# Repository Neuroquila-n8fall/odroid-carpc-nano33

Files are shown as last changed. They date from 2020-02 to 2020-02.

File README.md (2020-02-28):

# odroid-carpc-nano33
Derivate of odroid-carpc-due for the Arduino Nano 33 IoT
An Arduino Due project for controlling an Odroid N2 via BMW Keyfob and iDrive.

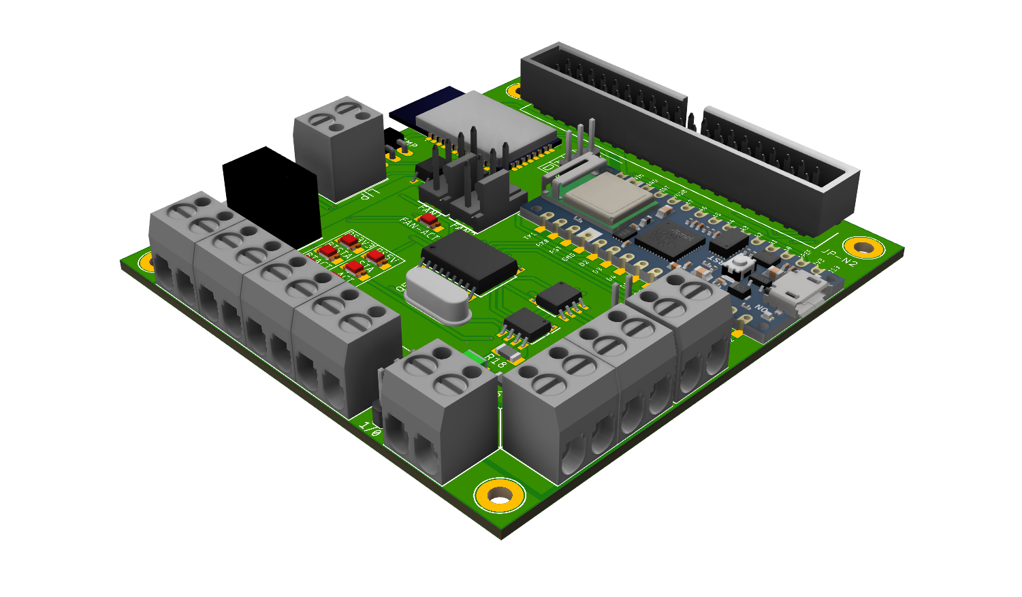
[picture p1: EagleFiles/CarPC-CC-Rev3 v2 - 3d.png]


## Hardware used
- BMW 1-Series 2009
- Arduino Nano 33 IoT
- Custom board design to incoorporate MCU, Bluetooth and Canbus logic on the same board
- iDrive 7-Button Controller 
- DS18B20 Temperature Probe
- LTC3780 Power Supply Module

## Purpose
This project is intended to support an Odroid N2 in its function as a car-pc. This also involves controlling the display brightness of the Vu7+ display by applying PWM signals to its backlight chip by reacting on the cars' light sensor on the windscreen.
As a bonus it's designed to support an iDrive controller as an input device for the Odroid to have comfortable access to the car-pc functions. To make it function properly an app called "Button Mapper" is used to react on F-Keys.
See: https://play.google.com/store/apps/details?id=flar2.homebutton

## Electrical Details
The brainbox of this module is a Arduino Nano 33 IoT which has its own 3v3 voltage regulator on board. To reduce stress it is supplied by the onboard 5V regulator from Recom. This 5V supply also powers the TJA1050 controller which needs 5V in order to generate the signals on the CAN-Bus. The Bluetooth module, MCP2515 and INA219 are supplied by the Arduino's voltage regulator.

The 5V Regulator is supplied by an external power supply and tolerates a maximum of 12V.

Because of the internal wiring of the Arduino, even the Fans will work when the Arduino is powered via USB. You will read 3V on the 12V rail if only the Arduino is plugged in to a Supply via USB. I've missed to include a Schottky Diode in order to prevent this behavior but it doesn't hurt either because everything is on the same potential and the internal regulator of the Arduino can deliver 1A continously. This also enables you to diagnose things on desk without hooking up everything to a external DC supply.

### Part selection
When selecting parts I've focused to select hose which are either AECQ100 certified or have an extended operating temperature range until at least 85°C. You should select parts for automotive use to ensure they last as long as possible.
```diff
- ATTENTION: Contrary to the schematics and board, the TCMT1100 up to TCMT1102 optocouplers can be used.
The TCMT1104 requires 10mA to trigger which the SAMD21 can't deliver. It's maximum current on a pin is 7mA
```
### Fan sockets
The PWM signal is tuned to work with all fans. I've tested bog standard 120mm fans as well as a dual high-pressure cisco switch fan. Please note that the socket delivers the voltage from the 12V rail. There is no possibility to power 5V fans here.

## 3rd Party Libraries used
I'm using a modified version of the BPLib that now supports sending and holding multiple keys. That's probably important for future tweaks. The original library only supports sending one single key and modifiers.
See: https://github.com/Neuroquila-n8fall/BPLib

Also: Seeedstudios Canbus Shield library
See: https://github.com/Seeed-Studio/CAN_BUS_Shield

## Usage
### Intended Usage & prerequisites
The main key aspect of the layout is to connect an external power supply which is supplied by the battery of the car through the board. The intention behind this is to keep everything safely connected. Cars are very flammable and therefore the top priority has to be that there is no risk of loose, uninsulated wires dangling around!

A DS18B20 temperature probe is required in order to keep track of the temperatures of the pc and control the fans accordingly.

### Wiring
This new revision has everything on board which makes wiring very easy. It also minimizes the amount of wiring.
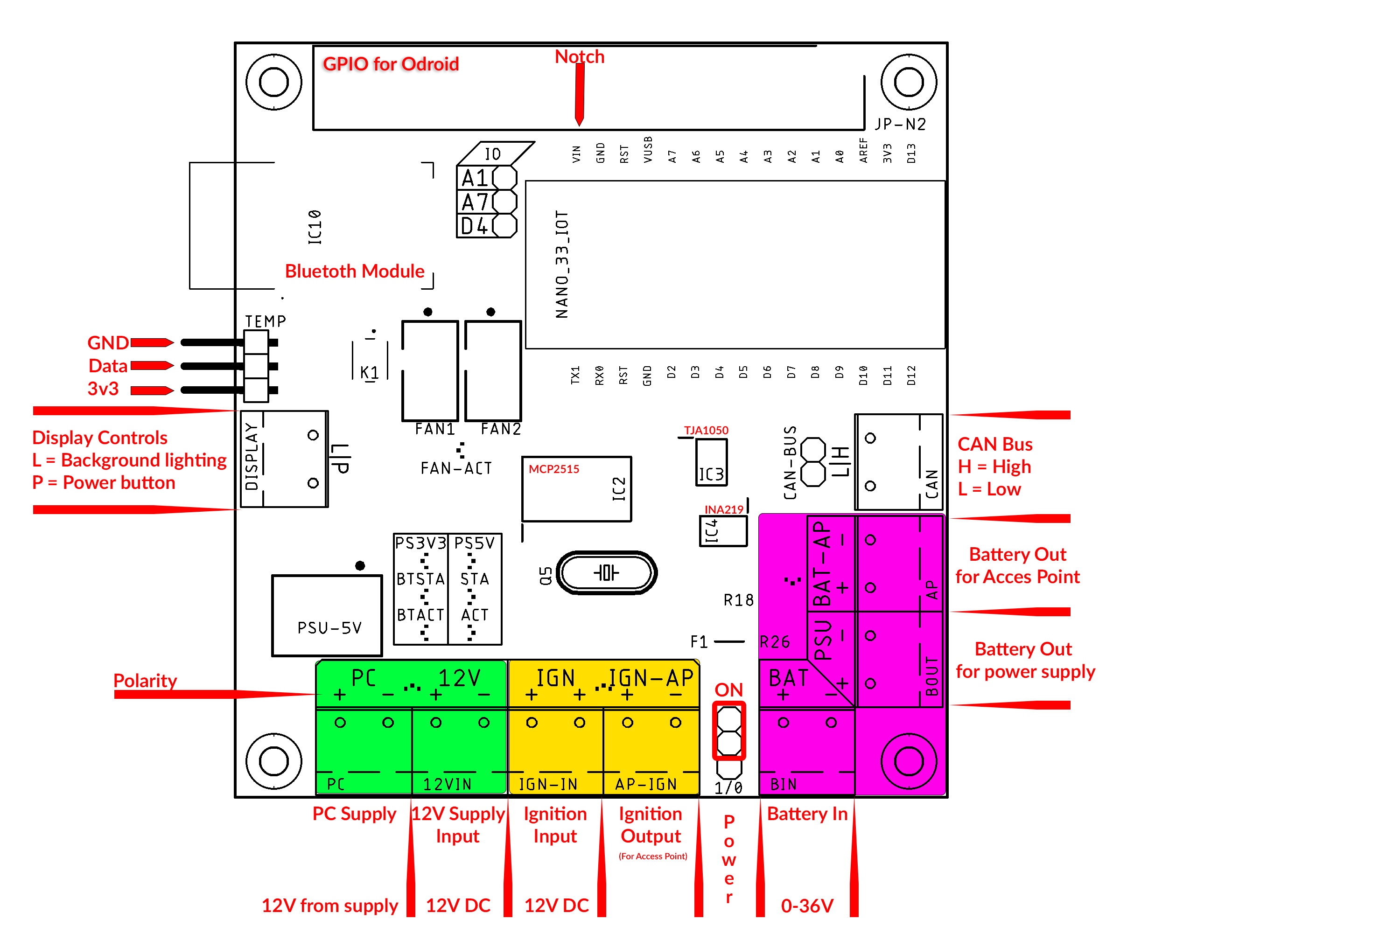
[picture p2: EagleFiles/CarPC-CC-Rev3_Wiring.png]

All of the terminals have a Description on the bottom which usually is hidden by the terminal itself. That's why a more descriptive text is added to the top.
You'll find a Terminal for the following auxillary devices:
- Display (VU7A+): One Output for controlling the background lighting and one for triggering the power button
- CAN-Bus: You can hook up your K-Can to the screw terminal or the pin headers behind.
- PC: This is the output for the Odroid. It receives power directly from the 12V terminal
- 12V: Power supply input from an external regulated power supply. I heavily recommend a supply board with the LTC3780 chip.
- IGN: Ignition. Two terminals are available because we only need one positive input. In case you want to hook up something on the ignition, this is the right place
- IGN-AP: Ignition output for Access Points. I'm using the Teltonika RUT850 which needs this supply in order to power up and down on itself
- BAT: Battery Input. Used by the control logic to check for voltage levels and also delivers power to the DC Supply
- PSU (BOUT): Battery Out. Intended to be used as Output to the power supply. This Terminal is switched by the "1/0" pin header between"IGN-AP2 and "BAT"
- BAT-AP: Used by the Teltonika access point as permanent supply

#### Color blocks explained
- Green: Shared 12v Rail
- Orange/Yellow: Shared Ignition Rail
- Purple: Shared Battery Rail

### Parameters
Parameters are described inside the source file "main.h" (https://github.com/Neuroquila-n8fall/odroid-carpc-nano33/blob/master/src/main.h)
Everything is well tested and works right out of the box. The prototype is already reaching one year of service on my car and shares the same code base.

### I2C
There are two solder pads "SCL-N" and "SDA-N" on the bottom to be bridged when you want to establish I2C communication between the Odroid N2 and the Arduino. This will join the N2 to the Arduino I2C bus. Important: The Arduino is the bus master!
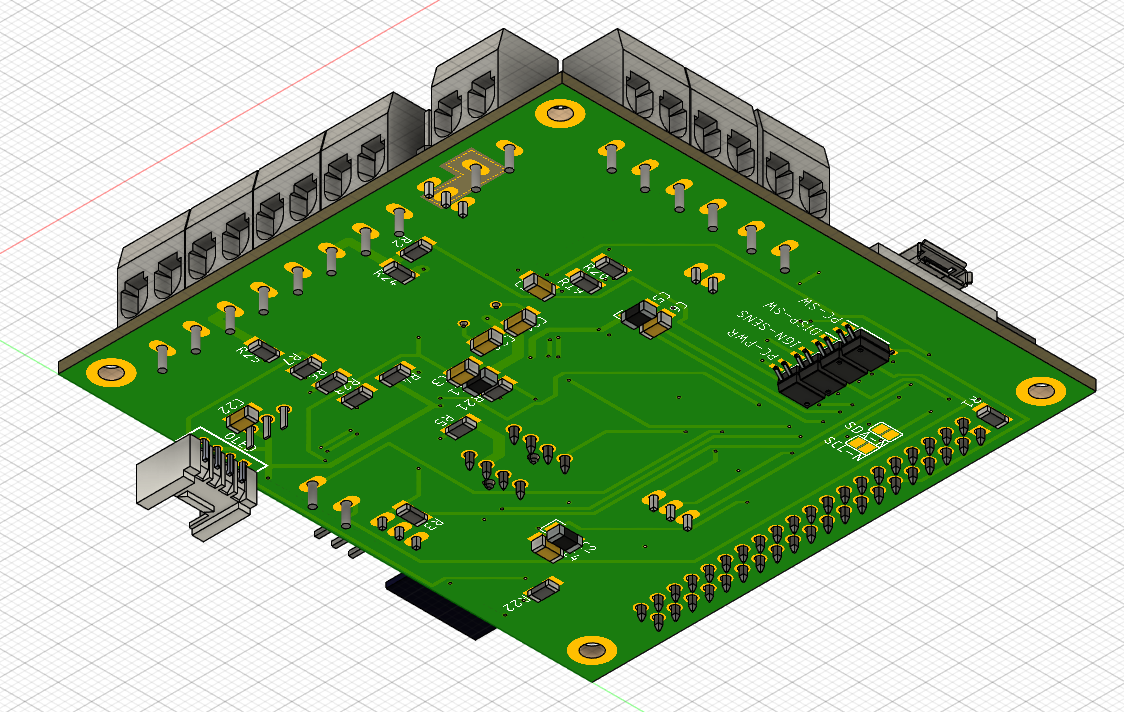
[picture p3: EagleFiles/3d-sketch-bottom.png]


### First-Run
#### Bluetooth Module Setup
Before uploading the sketch to the Arduino, you should head over to the setup section and uncomment the line "initalSetup()". Then, head over to the function and customize the name of the device and PIN. This will then set the required settings on the next startup of the Arduino on the bluetooth module so it works as intended. You may also use a Serial redirection sketch to enter the commands yourself or tweak things.
After that you should comment the section again and re-upload the sketch.

## Functions & Behaviour
### Startup
When you open the car by keyfob, the PC will be started by pulling down the power button GPIO pin on the Odroid for a second. This will turn on the Odroid.
### Shutdown
When you close the car by keyfob, it will pull down the GPIO pin again but now for several seconds which triggers the shutdown routine of the Odroid so it shuts down gracefully.
### Queuing
You can queue exactly one action by pressing "open" or "close" on the keyfob respectively. 

What does this mean? 

This means that if you want to take something out of the car and leave it again, you will have to press "open" and "close" in a rather short timespan. usually this would mean the startup process will be terminated or the PC will run until you enter the car again or press the "close" button again after the Pc booted up. Instead the controller stores the second action and waits for the PC to boot up and then shuts it down gracefully again. Because we never now when a "open" is followed by driving or just for accessing the car for a short duration this system prevents ungraceful shutdowns or battery drain.

Vice-Versa this means when closing the car and re-opening it again, the Odroid will be started again shortly. 
### Battery Monitoring (WIP)
- If the battery drops below a certain voltage, the Odroid will be shut down gracefully
- Fans will be shut down
- Everything else stays active. I'm planning to save energy by only enabling WiFi if the ignition is on.
### WiFi
- Wifi is included and active and intended to provide IoT functionality in the future. I have yet to think about useful scenarios where this feature comes in handy
- As of now WiFi is used to synchronize the RTC via NTP
### iDrive Controls
If an iDrive Controller is placed on the CAN Network, the controller will start to communicate with the network. The Sketch has the correct facilities in place to keep it awake and enable the rotation encoder. I've tried to resemble the original behavior of the iDrive controller.
- Rotation is scrolling up and down respectively
- Pushing the Menu button or the knob equals "Enter"
- Pushing the knob in any direction will emulate a directional arrow key so you can navigate in two dimensions between UI elements.

Things worthy of noting:
- Some apps don't come with keyboard support. Android is a touch-centric OS and therefore only a few devs implement full fledged keyboard control. Apps that work well are: Sygic, Spotify, Torque, Google Maps, Chrome
- You should use the button mapper app to implement extended features like return to home by long press and stuff like that
- Mapping buttons to apps can be done via Odroid Settings
### Multi Function Steering Wheel Buttons
Native support is integrated which means you can skip music tracks with the arrow keys and fast-forward and rewind when holding those buttons.
### Display Brightness Adjustment
The controller fetches messages from the CAN network from the RLS module (Regen Licht Sensorik) which sits, if fitted, on the windscreen behind the rearview mirror. It then maps those values to control the screen brightness of the VU7a display. The control values are proven but may vary between cars.

## Signalling & Diagnosis
There are plenty of status led on the board:
- One for the battery rail which indicates that the battery is connected
- One for the 12v rail to indicate a working power supply input
- One for the ignition rail so you know if the ignition input works
- One for the 3v3 and 5v rails 
- 2 for the bluetooth module: BTACT = Activity: Tells you what the module is doing, BTSTA = Status: Off when a device is connected
- 2 for the Arduino: STA tells you if the PC is running, ACT tells you if there is activity on the CAN-Bus and pulses when nothing is going on
- One for the fans: On if the relay is opened and fans are enabled
- There is also an optional OLED Grove connector. Because of timing issues I removed it from the project but it can be used as a diagnostical device if needed. Since 5v and I2C is supplied there, you can hook up other stuff to this port.

## Known Issues
- ~~As soon as the car battery is depleted, the arduino will write value 0 to the display brightness pin when the engine starts or doors are fully opened and closed. I have yet to understand why on earth this is happening even when the engine is already running. I can only think of a solution where the brightness is updated frequently, like 10 seconds or so.~~

**Solved: Explicit correction of values that are out of range. When the car has recovered from a very low voltage level, the light sensor reports values that are not mapped correctly by the "map" function. Such values are now being overwritten**
- ~~When the car is not shut and goes into hibernation and the car pc is still running, it might happen that the display goes dark. This might also be related to the aforementioned problem and may point to an integer overflow issue on the brightness calculation. Maybe the sensor on the windshield (RLS Control Module) sends some crazy data when it goes into hibernation.~~

**Solved: Same issue and solution as above**

- Sometimes the "restart" feature of the queuing mechanism doesn't work. Odroid will then start after the ignition is on.

- Apparently setting the PWM clock to 25kHz in order to control PWM fans also affects the display brightness pin somehow. This is something I didn't see coming. Maybe another pin configuration is needed...

## Questions I got asked...
Why all the hassle if I could just simply upgrade the car to the official iDrive?
Because I always felt the need to include a full blown car pc into my car. Upgrading to iDrive wasn't an option due to the fact that this system is just too limited. If I had a recent model, this wouldn't be a problem but sitting on a rather "old" car leaves one without options. I want a browsable music library with cloud sync, internet, the precious Torque app, ...all the good stuff!
The icing on the cake was the decision to go the extra mile and swap the center console and install an iDrive 7-Button control unit. It looks like OEM but it does much, much more.

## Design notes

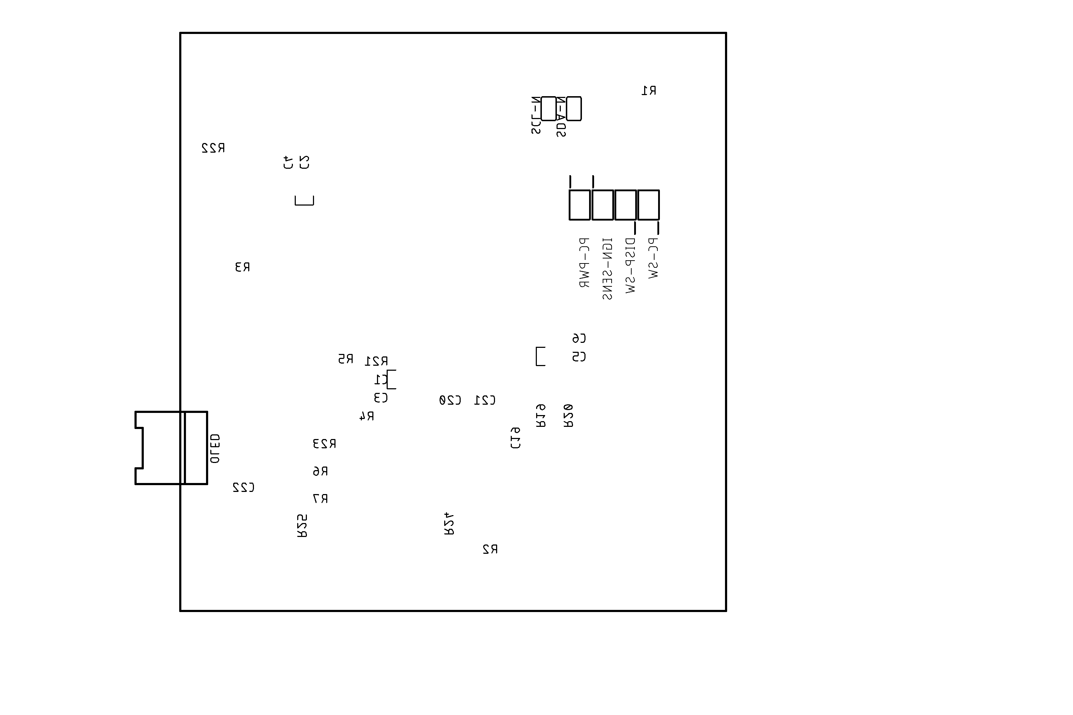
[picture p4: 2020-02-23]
EagleFiles/CarPC-CC-Rev3_bottom.png

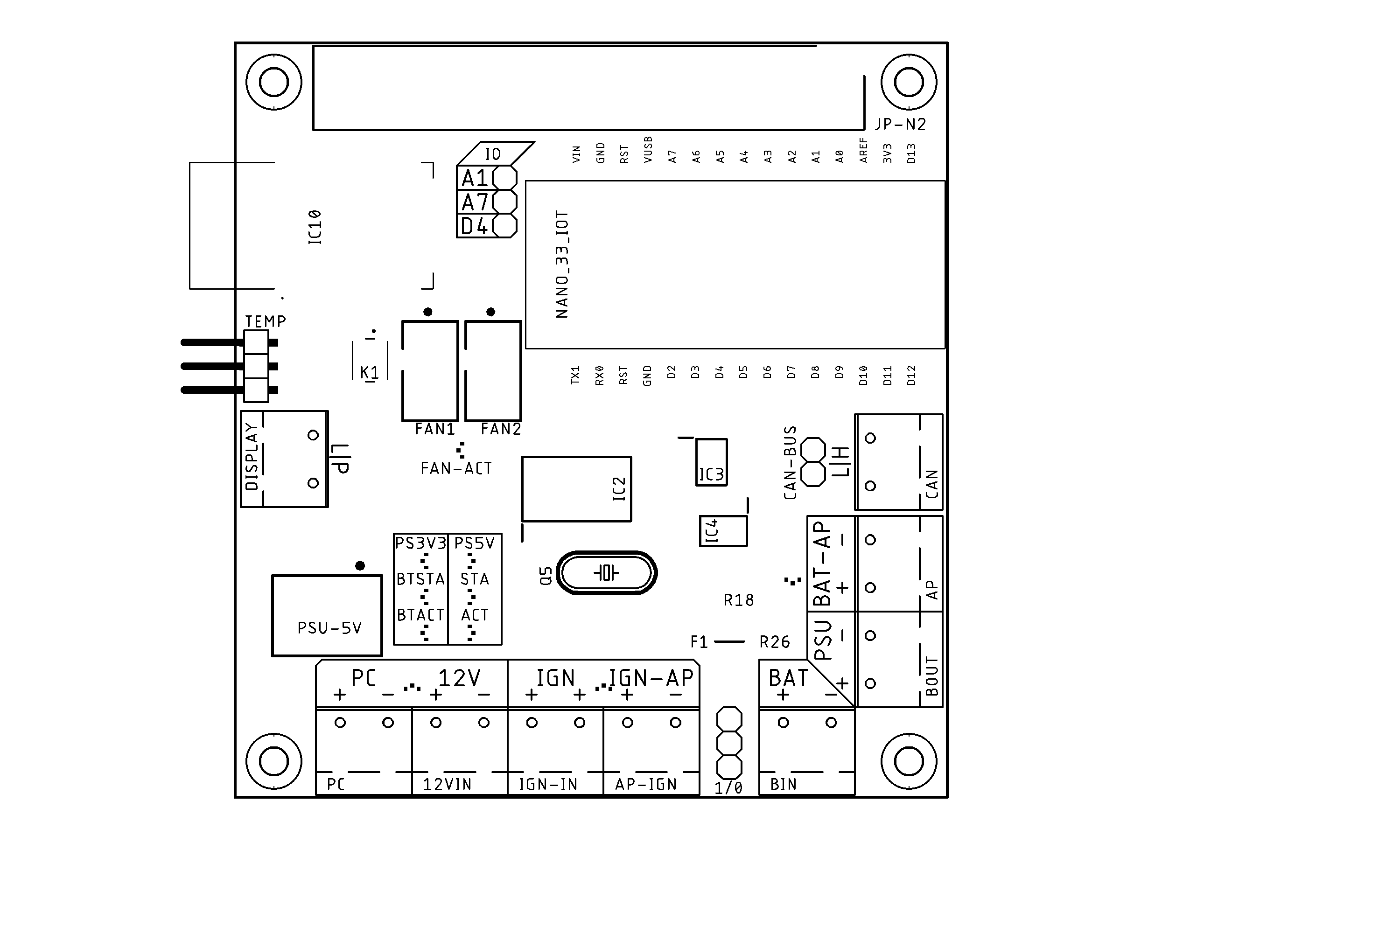
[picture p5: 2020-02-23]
EagleFiles/CarPC-CC-Rev3.png

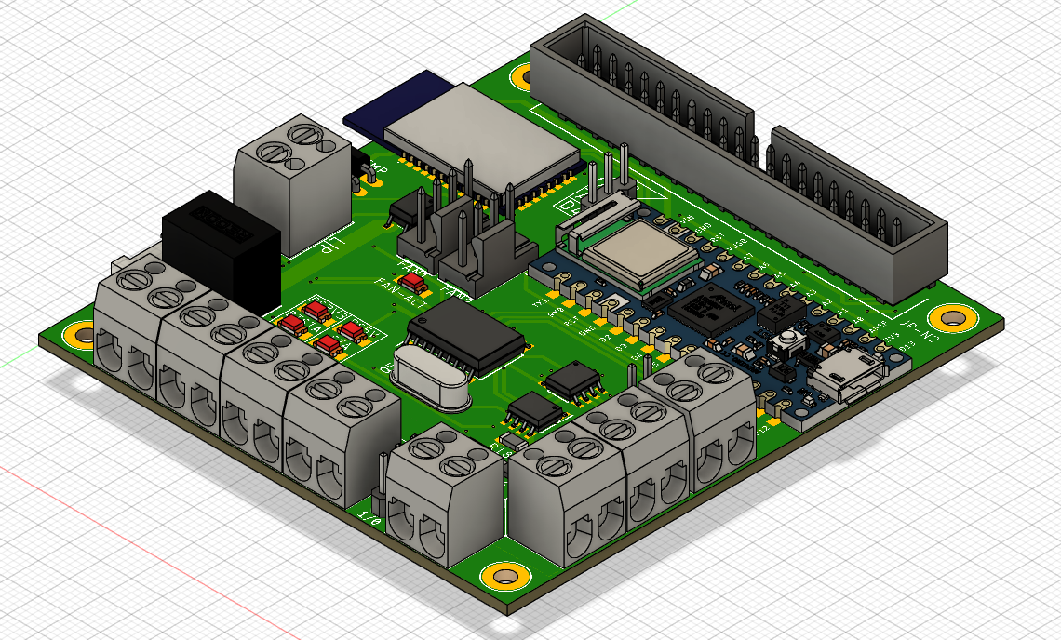
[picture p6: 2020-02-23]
EagleFiles/3d-sketch-top.png

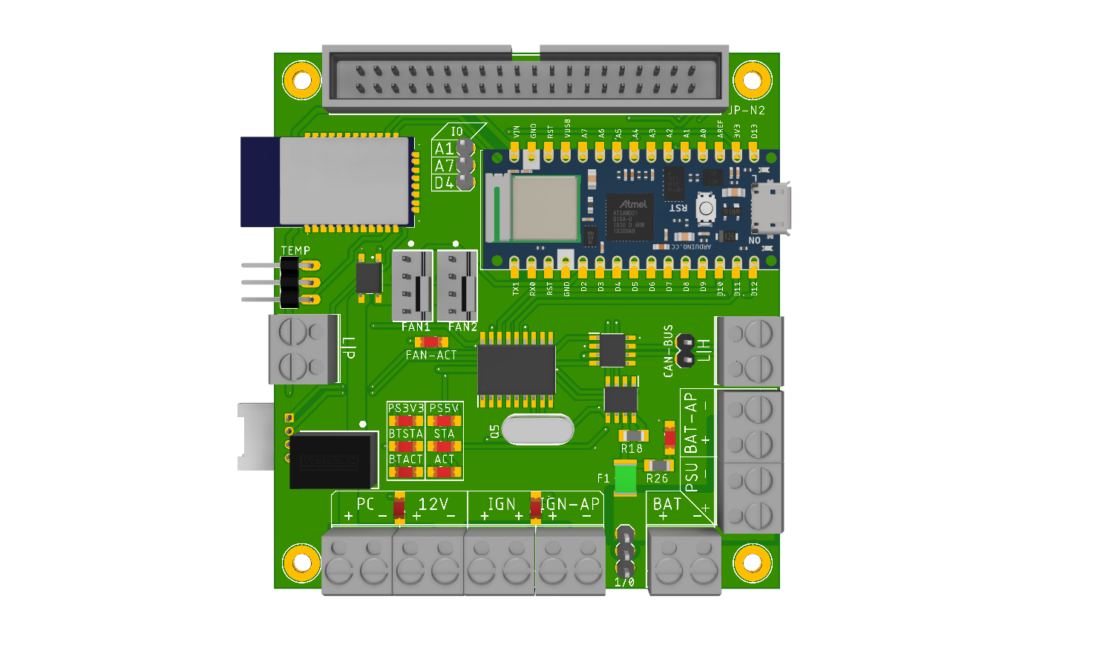
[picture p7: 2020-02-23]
EagleFiles/CarPC-CC-Rev3 v2 3D Top.png

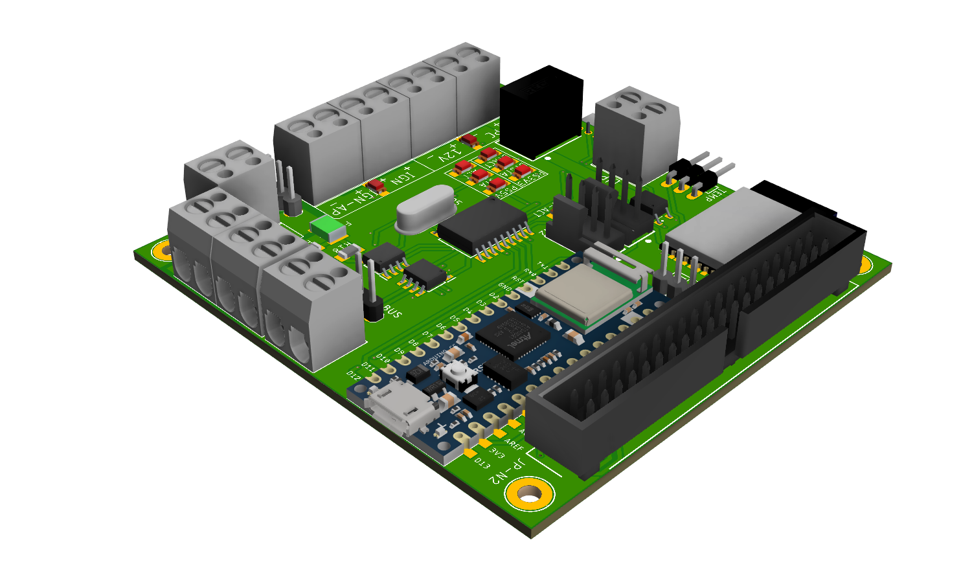
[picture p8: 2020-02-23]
EagleFiles/CarPC-CC-Rev3 v2 - 3D 2.png

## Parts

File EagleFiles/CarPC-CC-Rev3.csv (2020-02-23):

Qty | Value | Device | Package | Parts | Description | ALLIED_NUMBER | ALLIED_PRICE-STOCK | DESCRIPTION | HEIGHT | MANUFACTURER_NAME | MANUFACTURER_PART_NUMBER | MF | MOUSER_PART_NUMBER | MOUSER_PRICE-STOCK | MPN | OC_FARNELL | OC_NEWARK | POPULARITY | RS_PART_NUMBER | RS_PRICE-STOCK | SPICEPREFIX | VALUE
1 |  | PINHD-1X2 | 1X02 | CAN-BUS | PIN HEADER |  |  |  |  |  |  |  |  |  |  |  |  | 98
2 |  | PINHD-1X3 | 1X03 | 1/0, IO | PIN HEADER |  |  |  |  |  |  |  |  |  |  |  |  | 92
1 |  | PINHD-1X3/90 | 1X03/90 | TEMP | PIN HEADER |  |  |  |  |  |  |  |  |  |  |  |  | 17
2 |  | SJ | SJ | SCL-N, SDA-N | SMD solder JUMPER |  |  |  |  |  |  |  |  |  |  |  |  | 33
9 |  | W237-02P | W237/132 | 12VIN, AP, AP-IGN, BIN, BOUT, CAN, DISPLAY, IGN-IN, PC | WAGO SREW CLAMP |  |  |  |  |  |  |  |  |  |  | unknown | unknown | 10
1 | 0.1uF, 1206 | C-EUC1206 | C1206 | C19 | CAPACITOR, European symbol |  |  |  |  |  |  |  |  |  |  |  |  | 54 |  |  | C
1 | 100k, 1206 | R-EU_R1206 | R1206 | R18 | RESISTOR, European symbol |  |  |  |  |  |  |  |  |  |  |  |  | 41 |  |  | R
2 | 100nF | C-EUC1206 | C1206 | C3, C6 | CAPACITOR, European symbol |  |  |  |  |  |  |  |  |  |  |  |  | 54 |  |  | C
4 | 10k, 1206 | R-EU_R1206 | R1206 | R19, R20, R21, R22 | RESISTOR, European symbol |  |  |  |  |  |  |  |  |  |  |  |  | 41 |  |  | R
3 | 10uF | CPOL-1206 | C1206 | C1, C2, C5
1 | 10uF, 1206 | C-EUC1206 | C1206 | C22 | CAPACITOR, European symbol |  |  |  |  |  |  |  |  |  |  |  |  | 54 |  |  | C
1 | 16MHz | CRYSTALHC49S | HC49-S | Q5 | CRYSTAL |  |  |  |  |  |  |  |  |  |  | 1667008 | unknown | 49
6 | 1k, 1206 | R-EU_R1206 | R1206 | R1, R2, R5, R24, R25, R26 | RESISTOR, European symbol |  |  |  |  |  |  |  |  |  |  |  |  | 41 |  |  | R
1 | 1uF | C-EUC1206 | C1206 | C4 | CAPACITOR, European symbol |  |  |  |  |  |  |  |  |  |  |  |  | 54 |  |  | C
2 | 22pF, 1206 | C-EUC1206 | C1206 | C20, C21 | CAPACITOR, European symbol |  |  |  |  |  |  |  |  |  |  |  |  | 54 |  |  | C
1 | 270R, 1206 | R-EU_R1206 | R1206 | R23 | RESISTOR, European symbol |  |  |  |  |  |  |  |  |  |  |  |  | 41 |  |  | R
3 | 330R, 1206 | R-EU_R1206 | R1206 | R4, R6, R7 | RESISTOR, European symbol |  |  |  |  |  |  |  |  |  |  |  |  | 41 |  |  | R
1 | 4.7k, 1206 | R-EU_R1206 | R1206 | R3 | RESISTOR, European symbol |  |  |  |  |  |  |  |  |  |  |  |  | 41 |  |  | R
2 | 47053-1000 | 47053-1000 | 47053-1000 | FAN1, FAN2 | MOLEX - 47053-1000 - HEADER, 4POS, 1ROW, 2.54MM |  |  | MOLEX - 47053-1000 - HEADER, 4POS, 1ROW, 2.54MM | mm | Molex | 47053-1000 |  | 538-47053-1000 | https://www.mouser.com/Search/Refine.aspx?Keyword=538-47053-1000
1 | 4P-2.0-90D | GROVE-CONNECTOR-DIP-90D(4P-2.0) | HW4-2.0-90D | OLED | 320110034 |  |  |  |  |  |  |  |  |  |  |  |  |  |  |  |  | 4P-2.0-90D
1 | 70246-4001 | 70246-4001 | SHDR40W94P254_2X20_5842X889X92 | JP-N2 | Header 2.54mm, dual row, vertical, 40w Molex C-GRID Series, Series Number 70246, 2.54mm Pitch 40 Way 2 Row Straight PCB Header, Solder Termination, 2.5A | 70373451 | https://www.alliedelec.com/molex-incorporated-70246-4001/70373451/ | Header 2.54mm, dual row, vertical, 40w Molex C-GRID Series, Series Number 70246, 2.54mm Pitch 40 Way 2 Row Straight PCB Header, Solder Termination, 2.5A | 9.27mm | Molex | 70246-4001 |  | 538-70246-4001 | https://www.mouser.com/Search/Refine.aspx?Keyword=538-70246-4001 |  |  |  |  | 6701825P | http://uk.rs-online.com/web/p/products/6701825P
1 | Arduino-Nano-33-IOT | ARDUINONANO33IOTARDUINONANO33IOT_SMD | ARDNANO33IOT_SMD | NANO_33_IOT
1 | G3VM-61VR(TR) | G3VM-61VR(TR) | G3VM61VRTR | K1 | Solid State Relays - PCB Mount MOSFET Relay SOP4 60V 1400mA 1 Form A | 71240743 | https://www.alliedelec.com/omronelectroniccomponents-g3vm-61vr-tr/71240743/ | Solid State Relays - PCB Mount MOSFET Relay SOP4 60V 1400mA 1 Form A | 2.2mm | Omron Electronics | G3VM-61VR(TR) |  | 653-G3VM-61VRTR | https://www.mouser.com/Search/Refine.aspx?Keyword=653-G3VM-61VRTR
1 | INA219AIDR | INA219AIDR | SOIC127P600X175-8N | IC4 | 26-V, Bidirectional, Zero-Drift, High-Side, I2C Out Current/Power Monitor |  |  | 26-V, Bidirectional, Zero-Drift, High-Side, I2C Out Current/Power Monitor | 1.75mm | Texas Instruments | INA219AIDR |  | 595-INA219AIDR | https://www.mouser.com/Search/Refine.aspx?Keyword=595-INA219AIDR
5 | LTST-C150CKT | LEDCHIPLED_1206 | CHIPLED_1206 | BATT-LED, IGN, PS3V3, PS5V, PS12V | LED |  |  |  |  |  |  |  |  |  |  |  |  | 28
2 | LTST-C150TBKT | LEDCHIPLED_1206 | CHIPLED_1206 | BTACT, BTSTA | LED |  |  |  |  |  |  |  |  |  |  |  |  | 28
3 | LTW-C230DS | LEDCHIPLED_1206 | CHIPLED_1206 | ACT, FAN-ACT, STA | LED |  |  |  |  |  |  |  |  |  |  |  |  | 28
1 | MCP2515-I_SO | MCP2515-I_SO | SOIC127P1030X265-18N | IC2 | CAN Controller SPI data filtering SO18 |  |  | CAN Controller SPI data filtering SO18 | 2.65mm | Microchip | MCP2515-I/SO |  | 579-MCP2515-I/SO | https://www.mouser.com/Search/Refine.aspx?Keyword=579-MCP2515-I%2FSO
1 | MF-MSMF250_16X-2 | MF-MSMF250_16X-2 | FUSC4632X160N | F1 | PTC Resettable Fuse 2.5A(hold) 5A(trip) 16V 100A 1.2W 5s 0.015Ohm SMD Solder Pad 1812 T/R Automotive | 70153471 | https://www.alliedelec.com/bourns-mf-msmf250-16x-2/70153471/ | PTC Resettable Fuse 2.5A(hold) 5A(trip) 16V 100A 1.2W 5s 0.015Ohm SMD Solder Pad 1812 T/R Automotive | 1.6mm | Bourns | MF-MSMF250/16X-2 |  | 652-MF-MSMF250/16X-2 | https://www.mouser.com/Search/Refine.aspx?Keyword=652-MF-MSMF250%2F16X-2 |  |  |  |  | 8978967P | http://uk.rs-online.com/web/p/products/8978967P
4 | MOUNT-PAD-ROUND2.8 | MOUNT-PAD-ROUND2.8 | 2,8-PAD | H1, H2, H3, H4 | MOUNTING PAD, round |  |  |  |  |  |  |  |  |  |  |  |  | 6
1 | R-78E5.0-1.0 | R-78E5.0-1.0 | R-78E5.0-1.0 | PSU-5V | Non-Isolated DC/DC Converters 8-28Vin 5V 1.0A THRU |  |  | Non-Isolated DC/DC Converters 8-28Vin 5V 1.0A THRU | mm | RECOM Power | R-78E5.0-1.0 |  | 919-R-78E5.0-1.0 | https://www.mouser.com/Search/Refine.aspx?Keyword=919-R-78E5.0-1.0 |  |  |  |  | 1446290P | http://uk.rs-online.com/web/p/products/1446290P
1 | RN42HID-I/RM | RN42HID-I_RM | RN42HIDIRM | IC10 | MICROCHIP - RN42HID-I/RM - BLUETOOTH MODULE, V2.1, 3MBPS | 70451526 | https://www.alliedelec.com/microchip-technology-inc-rn42hid-i-rm/70451526/ | MICROCHIP - RN42HID-I/RM - BLUETOOTH MODULE, V2.1, 3MBPS | 2mm | Microchip | RN42HID-I/RM |  | 765-RN42HID-I/RM | https://www.mouser.com/Search/Refine.aspx?Keyword=765-RN42HID-I%2FRM |  |  |  |  | 9123020 | http://uk.rs-online.com/web/p/products/9123020
4 | TCMT1102TCMT1102 | TCMT1102TCMT1102 | SOIC127P700X230-4N | DISP-SW, IGN-SENS, PC-PWR, PC-SW
1 | TJA1050T-CM/118 | TJA1050T_CM,118 | SOIC127P600X175-8N | IC3 | NXP - TJA1050T/CM,118 - CAN TRANSCEIVER, 1TX/RX, SOIC-8 |  |  | NXP - TJA1050T/CM,118 - CAN TRANSCEIVER, 1TX/RX, SOIC-8 | 1.75mm | Nexperia | TJA1050T/CM,118 |  | 771-TJA1050T/CM118 | https://www.mouser.com/Search/Refine.aspx?Keyword=771-TJA1050T%2FCM118

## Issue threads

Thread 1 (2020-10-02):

Renault Scenic III

dslthomas, 2020-10-02:
I'll copy my request in here:
So hats off! Brilliant! That's exactly what I'll try with my Scenic III. So far I've solved it like this:

https://www.youtube.com/watch?v=vN-myYNgF-c

and

https://www.youtube.com/watch?v=w6l-g9UskWk.

Unfortunately, that works rather poorly than right. Precisely because I have a car with automatic start & stop and the smartphone then shuts down. Unfortunately, I don't have an ignition plus in the passenger compartment.

Instead of the iDrive at BMW, I have the following keyboard which I would tap:

https://ibb.co/zNryJPp][img]https://i.ibb.co/zNryJPp/2020-09-27-11-29-24.jpg

Question: How realistic is it to adapt your project to my Renault?

Question: Do you also sell the finished circuit boards?I took a look - to have the circuit board produced, I would have to pay around 150 euros including the assembly. I don't have a problem with that at first, but I don't want to do that without knowing whether it can be adapted for my car.

Thanks and greetings from Hamburg.

----------- G E R M A N -------------
Ich kopiere meine Anfrage mal hier rein:
Also Hut ab! Genial! Genau das werde ich bei meinem Scenic III ebenfalls versuchen. Bisher habe ich das so gelöst:

https://www.youtube.com/watch?v=vN-myYNgF-c

und

https://www.youtube.com/watch?v=w6l-g9UskWk.

Leider funktioniert das eher schlecht als recht. Gerade weil ich einen Wagen mit Start&Stop Automatik habe und das Smartphone dann runter fährt. Ein Zündungsplus habe ich leider nicht im Fahrgastraum.

Statt dem iDrive bei BMW habe ich folgende Tastatur welche ich anzapfen würde:

https://ibb.co/zNryJPp][img]https://i.ibb.co/zNryJPp/2020-09-27-11-29-24.jpg

Frage: Wie realistisch ist es, dein Projekt auf meinen Renault zu adaptieren?

Frage: Verkaufst du die fertigen Platinen auch? Ich habe mal geschaut,- um die Platine produzieren zu lassen, müsste ich ca. 150 Euro inkl. der Bestückung zahlen. Damit habe ich erst einmal kein Problem, möchte das aber ungern tun, ohne zu wissen ob es für meinen Wagen zu adaptieren geht.

Danke und Gruß aus Hamburg.

Neuroquila-n8fall, 2020-10-03:
Hey,
um das Ganze ohne Zündungsplus umzusetzen müsstest du erstmal die CAN Nachrichten verstehen. Danach steht eigentlich alles offen. Schwierigkeiten die es zu bewältigen gibt sind eigentlich "nur" die folgenden:
- CAN Bus aufschlüsseln um zu wissen wann das Gerät aktiv oder inaktiv sein soll.
- Geräteanbindung an Arduino um es kontrolliert rauf- und runterfahren zu können. Am besten hat man dazu sowas wie einen Odroid da das Teil GPIOs hat um das kontrolliert durchführen zu können. Konsolenbefehle an ein Android schicken ist so eine Sache - ich hatte damit wenig Erfolg da die 5V Rail am Odroid keine Schotky Diode hat und somit der Arduino nicht feststellen kann, ob der Odroid aus ist, da ja immer Spannung an den Pins über die USB Verbindung anliegt!

Grundsätzlich lässt sich das bei jedem Fahrzeug umsetzen. Es ist die Frage wie viel Zeit und Energie dir zur Verfügung steht die Fahrzeugelektrik entsprechend anzupacken bzw. den CAN Bus. Der Sourcecode ist dahingehend auch modular genug aufgebaut um es für andere Zwecke adaptieren zu können.

Wir können uns da gerne mal drüber unterhalten. Schrieb mir dazu mal unter david-at-ginsbach.eu

Grüße aus dem Saarland! :)

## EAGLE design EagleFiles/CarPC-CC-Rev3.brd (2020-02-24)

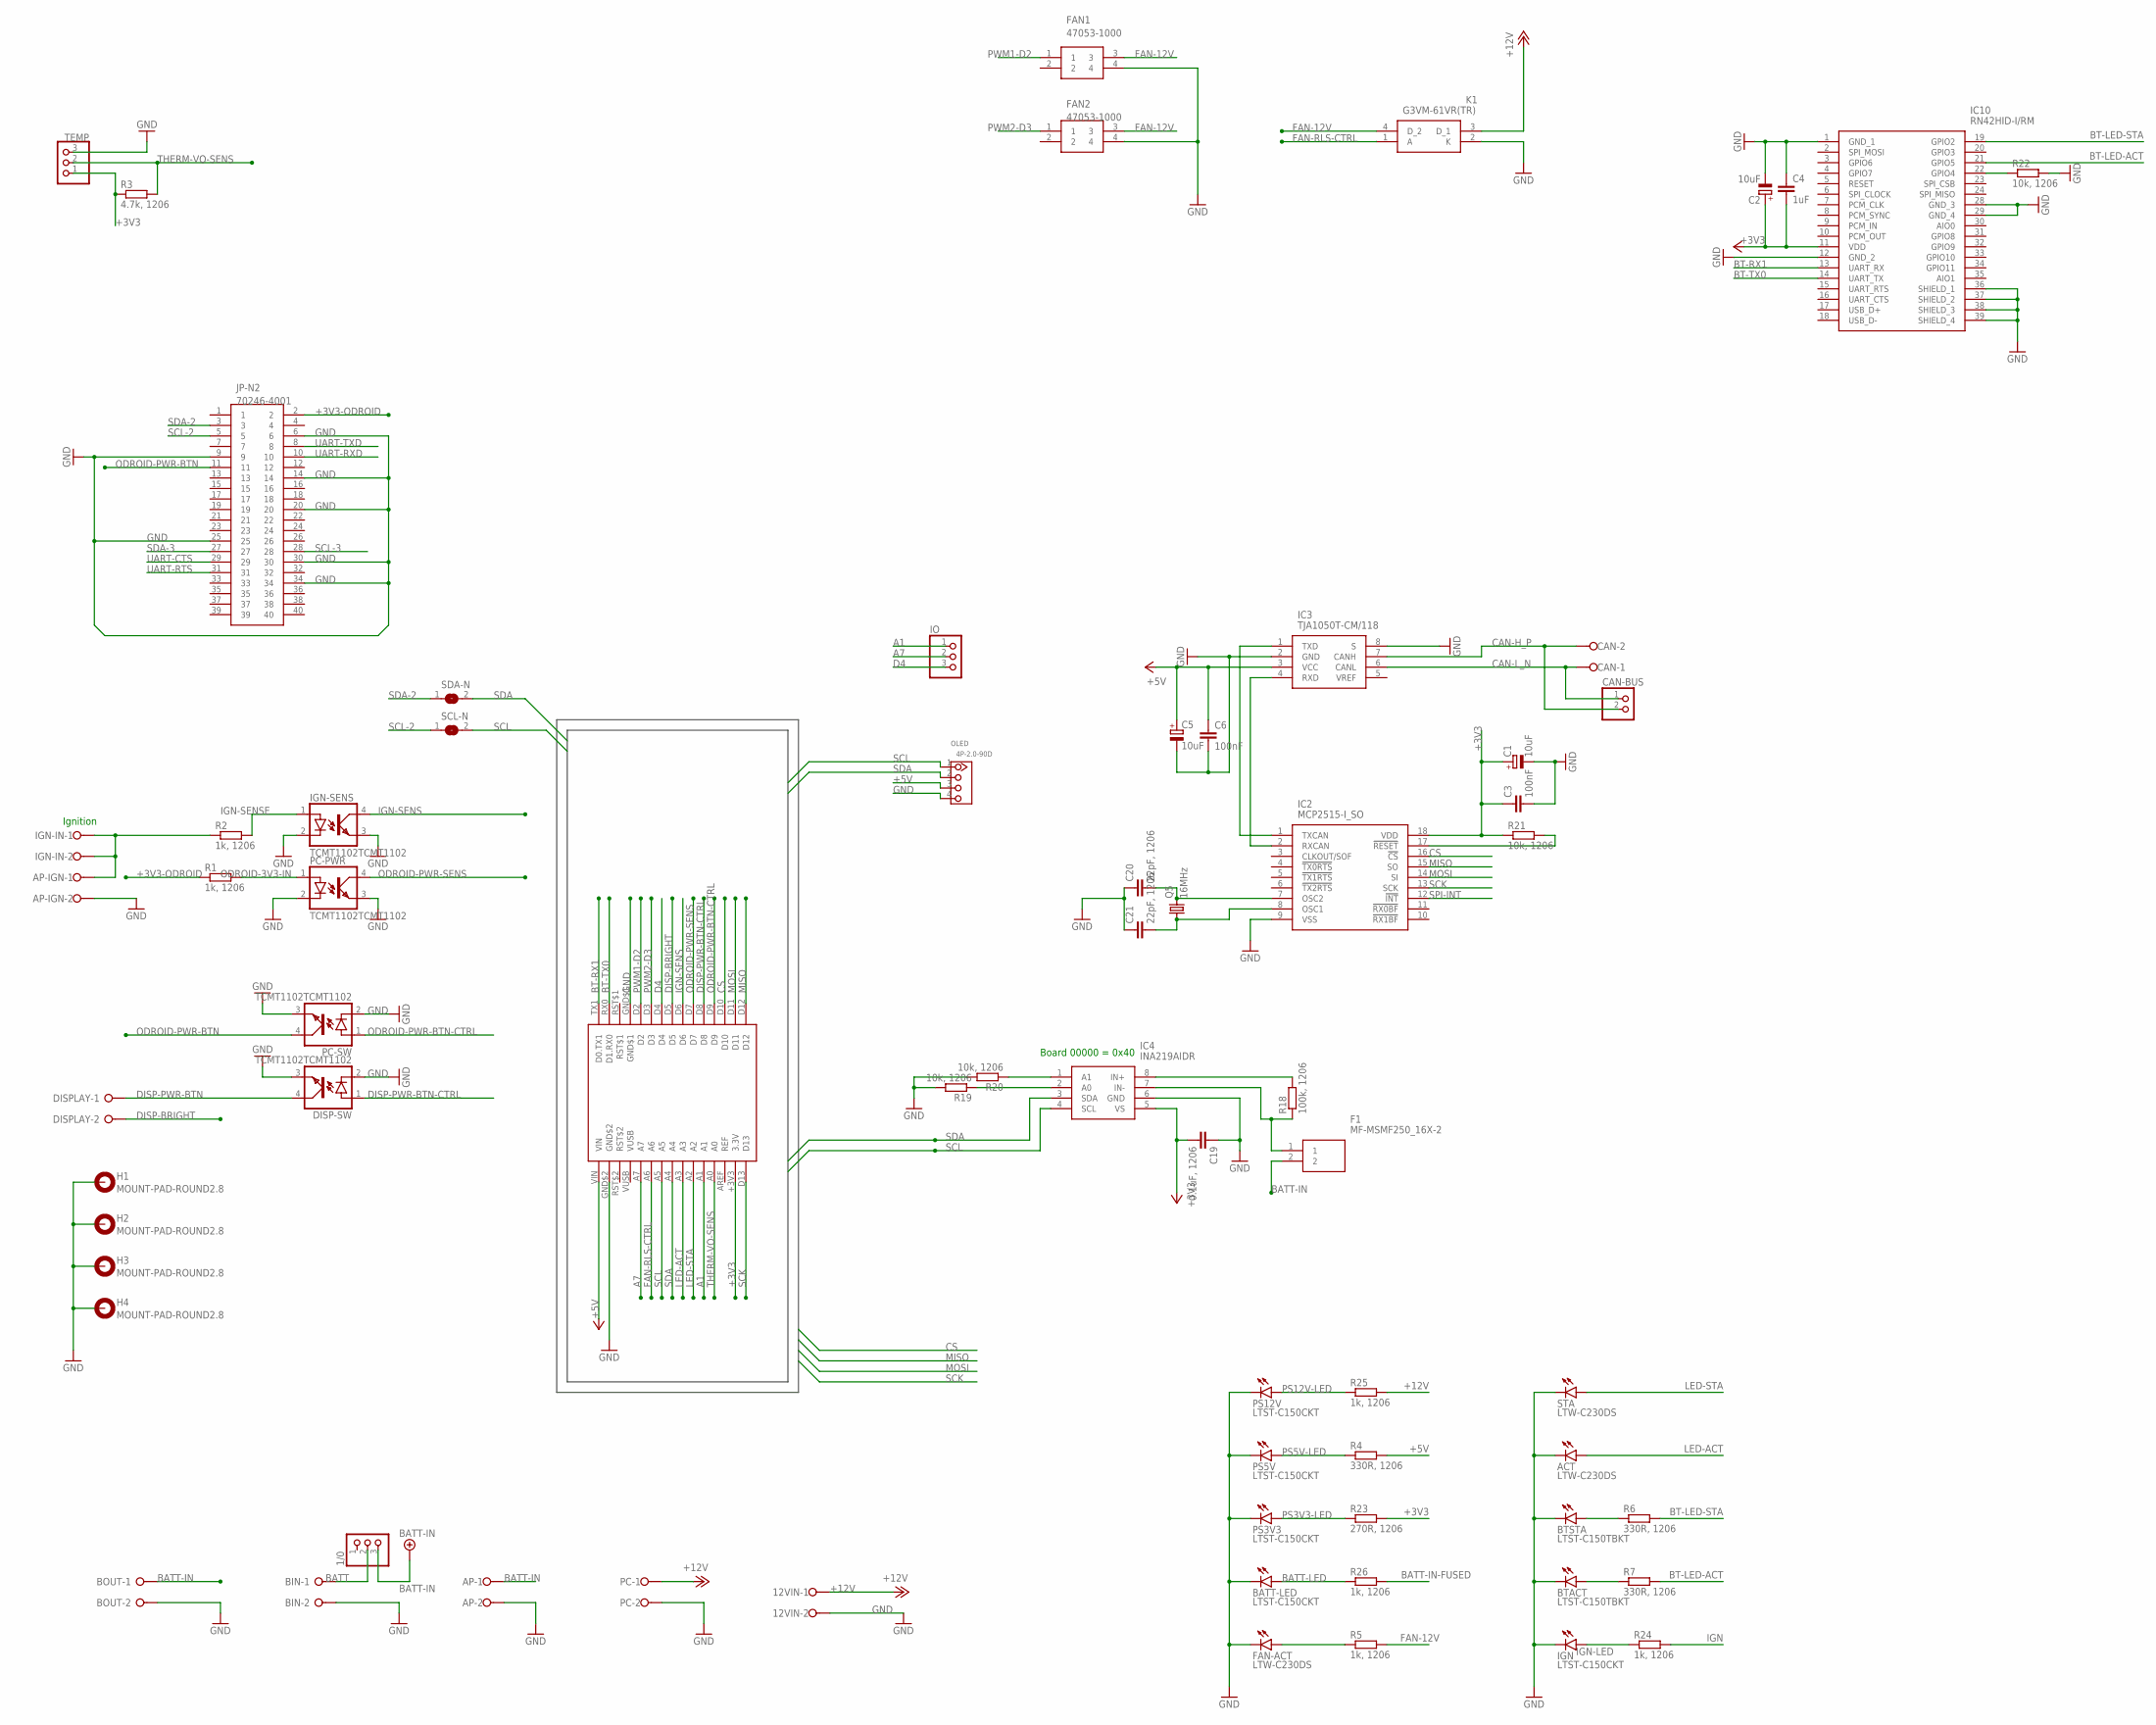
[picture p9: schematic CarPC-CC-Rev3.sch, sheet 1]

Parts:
1/0: PINHD-1X3; 1X03
12VIN: W237-02P; W237/132
ACT: LTW-C230DS; CHIPLED_1206
AP: W237-02P; W237/132
AP-IGN: W237-02P; W237/132
BATT-LED: LTST-C150CKT; CHIPLED_1206
BIN: W237-02P; W237/132
BOUT: W237-02P; W237/132
BTACT: LTST-C150TBKT; CHIPLED_1206
BTSTA: LTST-C150TBKT; CHIPLED_1206
C1, C2, C5: 10uF; C1206
C3, C6: 100nF; C1206
C4: 1uF; C1206
C19: 0.1uF, 1206; C1206
C20, C21: 22pF, 1206; C1206
CAN: W237-02P; W237/132
CAN-BUS: PINHD-1X2; 1X02
DISP-SW: TCMT1102TCMT1102; SOIC127P700X230-4N
DISPLAY: W237-02P; W237/132
F1: MF-MSMF250_16X-2; FUSC4632X160N
FAN1, FAN2: 47053-1000
FAN-ACT: LTW-C230DS; CHIPLED_1206
H1, H2, H3, H4: MOUNT-PAD-ROUND2.8; 2,8-PAD
IC2: MCP2515-I_SO; SOIC127P1030X265-18N
IC3: TJA1050T-CM/118; SOIC127P600X175-8N
IC4: INA219AIDR; SOIC127P600X175-8N
IC10: RN42HID-I/RM; RN42HIDIRM
IGN: LTST-C150CKT; CHIPLED_1206
IGN-IN: W237-02P; W237/132
IGN-SENS: TCMT1102TCMT1102; SOIC127P700X230-4N
IO: PINHD-1X3; 1X03
JP-N2: 70246-4001; SHDR40W94P254_2X20_5842X889X92
K1: G3VM-61VR(TR); G3VM61VRTR
NANO_33_IOT: Arduino-Nano-33-IOT; ARDNANO33IOT_SMD
OLED: 4P-2.0-90D; HW4-2.0-90D
PC: W237-02P; W237/132
PC-PWR: TCMT1102TCMT1102; SOIC127P700X230-4N
PC-SW: TCMT1102TCMT1102; SOIC127P700X230-4N
PS3V3, PS5V, PS12V: LTST-C150CKT; CHIPLED_1206
Q5: 16MHz; HC49-S
R1, R2, R5, R24, R25, R26: 1k, 1206; R1206
R3: 4.7k, 1206; R1206
R4, R6, R7: 330R, 1206; R1206
R18: 100k, 1206; R1206
R19, R20, R21, R22: 10k, 1206; R1206
R23: 270R, 1206; R1206
SCL-N: SJ
SDA-N: SJ
STA: LTW-C230DS; CHIPLED_1206
TEMP: PINHD-1X3/90; 1X03/90

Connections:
+3V3: C1.1 (+), C2.1 (+), C3.1, C4.2, C19.2, IC2.18 (VDD), IC4.5 (VS), IC10.11 (VDD), NANO_33_IOT.+3V3 (3.3V), R3.1, R21.1, R23.2, TEMP.1
+3V3-ODROID: JP-N2.2, R1.1
+5V: C5.1 (+), C6.1, IC3.3 (VCC), NANO_33_IOT.VIN, OLED.3, R4.2; also elsewhere on the board
+12V: 12VIN.1, K1.3 (D_1), PC.1, R25.2; also elsewhere on the board
A1: IO.1, NANO_33_IOT.A1
A7: IO.2, NANO_33_IOT.A7
BATT: 1/0.2, BIN.1
BATT-IN: 1/0.3, AP.1, BOUT.1, F1.2
BATT-IN-FUSED: F1.1, IC4.7 (IN-), R18.1, R26.2
BATT-LED: BATT-LED.A, R26.1
BT-ACTIVATE: IC10.22 (GPIO4), R22.1
BT-LED-ACT: IC10.21 (GPIO5), R7.2
BT-LED-STA: IC10.19 (GPIO2), R6.2
BT-RX1: IC10.13 (UART_RX), NANO_33_IOT.TX1 (D0.TX1)
BT-TX0: IC10.14 (UART_TX), NANO_33_IOT.RX0 (D1.RX0)
CAN-H_P: CAN.2, CAN-BUS.2, IC3.7 (CANH)
CAN-L_N: CAN.1, CAN-BUS.1, IC3.6 (CANL)
CS: IC2.16 (!CS), NANO_33_IOT.D10
D4: IO.3, NANO_33_IOT.D4
DISP-BRIGHT: DISPLAY.2, NANO_33_IOT.D5
DISP-PWR-BTN: DISP-SW.4 (COL), DISPLAY.1
DISP-PWR-BTN-CTRL: DISP-SW.1 (A), NANO_33_IOT.D8
FAN-12V: FAN1.3, FAN2.3, K1.4 (D_2), R5.2
FAN-RLS-CTRL: K1.1 (A), NANO_33_IOT.A6
GND: 12VIN.2, ACT.C, AP.2, AP-IGN.2, BATT-LED.C, BIN.2, BOUT.2, BTACT.C, BTSTA.C, C1.2 (-), C2.2 (-), C3.2, C4.1, C5.2 (-), C6.2, C19.1, C20.1, C21.1, DISP-SW.2 (K), DISP-SW.3 (EMI), FAN1.4, FAN2.4, FAN-ACT.C, H1.B2,8, H2.B2,8, H3.B2,8, H4.B2,8, IC2.9 (VSS), IC3.2 (GND), IC3.8 (S), IC4.6 (GND), IC10.1 (GND_1), IC10.12 (GND_2), IC10.28 (GND_3), IC10.29 (GND_4), IC10.36 (SHIELD_1), IC10.37 (SHIELD_2), IC10.38 (SHIELD_3), IC10.39 (SHIELD_4), IGN.C, IGN-SENS.2 (K), IGN-SENS.3 (EMI), JP-N2.6, JP-N2.9, JP-N2.14, JP-N2.20, JP-N2.25, JP-N2.30, JP-N2.34, K1.2 (K), NANO_33_IOT.GND$1, NANO_33_IOT.GND$2, OLED.4, PC.2, PC-PWR.2 (K), PC-PWR.3 (EMI), PC-SW.2 (K), PC-SW.3 (EMI), PS3V3.C, PS5V.C, PS12V.C, R19.2, R20.2, R22.2, STA.C, TEMP.3; also elsewhere on the board
IGN: AP-IGN.1, IGN-IN.1, IGN-IN.2, R2.1, R24.2
IGN-LED: IGN.A, R24.1
IGN-SENS: IGN-SENS.4 (COL), NANO_33_IOT.D6
IGN-SENSE: IGN-SENS.1 (A), R2.2
INA-0X40-ADDR0: IC4.2 (A0), R19.1
INA-0X40-ADDR1: IC4.1 (A1), R20.1
LED-ACT: ACT.A, NANO_33_IOT.A3
LED-STA: NANO_33_IOT.A2, STA.A
MCP-OSC1: C21.2, IC2.8 (OSC1), Q5.1
MCP-OSC2: C20.2, IC2.7 (OSC2), Q5.2
MCP-RESET: IC2.17 (!RESET), R21.2
MCP-TJA-RX: IC2.2 (RXCAN), IC3.4 (RXD)
MCP-TJA-TX: IC2.1 (TXCAN), IC3.1 (TXD)
MISO: IC2.15 (SO), NANO_33_IOT.D12
MOSI: IC2.14 (SI), NANO_33_IOT.D11
unnamed: FAN-ACT.A, R5.1
unnamed: BTSTA.A, R6.1
unnamed: BTACT.A, R7.1
ODROID-3V3-IN: PC-PWR.1 (A), R1.2
ODROID-PWR-BTN: JP-N2.11, PC-SW.4 (COL)
ODROID-PWR-BTN-CTRL: NANO_33_IOT.D9, PC-SW.1 (A)
ODROID-PWR-SENS: NANO_33_IOT.D7, PC-PWR.4 (COL)
PS3V3-LED: PS3V3.A, R23.1
PS5V-LED: PS5V.A, R4.1
PS12V-LED: PS12V.A, R25.1
PWM1-D2: FAN1.1, NANO_33_IOT.D2
PWM2-D3: FAN2.1, NANO_33_IOT.D3
SCK: IC2.13 (SCK), NANO_33_IOT.D13
SCL: IC4.4 (SCL), NANO_33_IOT.A5, OLED.1, SCL-N.2
SCL-2: JP-N2.5, SCL-N.1
SCL-3: JP-N2.28
SDA: IC4.3 (SDA), NANO_33_IOT.A4, OLED.2, SDA-N.2
SDA-2: JP-N2.3, SDA-N.1
SDA-3: JP-N2.27
SHUNT+: IC4.8 (IN+), R18.2
SPI-INT: IC2.12 (!INT)
THERM-VO-SENS: NANO_33_IOT.A0, R3.2, TEMP.2
UART-CTS: JP-N2.29
UART-RTS: JP-N2.31
UART-RXD: JP-N2.10
UART-TXD: JP-N2.8

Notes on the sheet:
Ignition
Board 00000 = 0x40

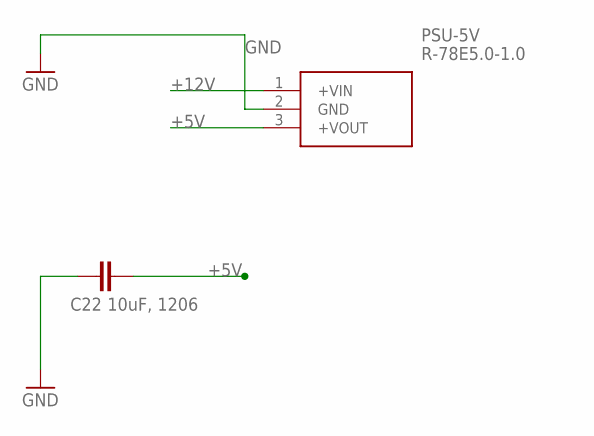
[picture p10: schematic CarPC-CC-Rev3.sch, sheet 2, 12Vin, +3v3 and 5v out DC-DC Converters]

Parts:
C22: 10uF, 1206; C1206
PSU-5V: R-78E5.0-1.0

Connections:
+5V: C22.2, PSU-5V.3 (+VOUT); also elsewhere on the board
+12V: PSU-5V.1 (+VIN); also elsewhere on the board
GND: C22.1, PSU-5V.2 (GND); also elsewhere on the board

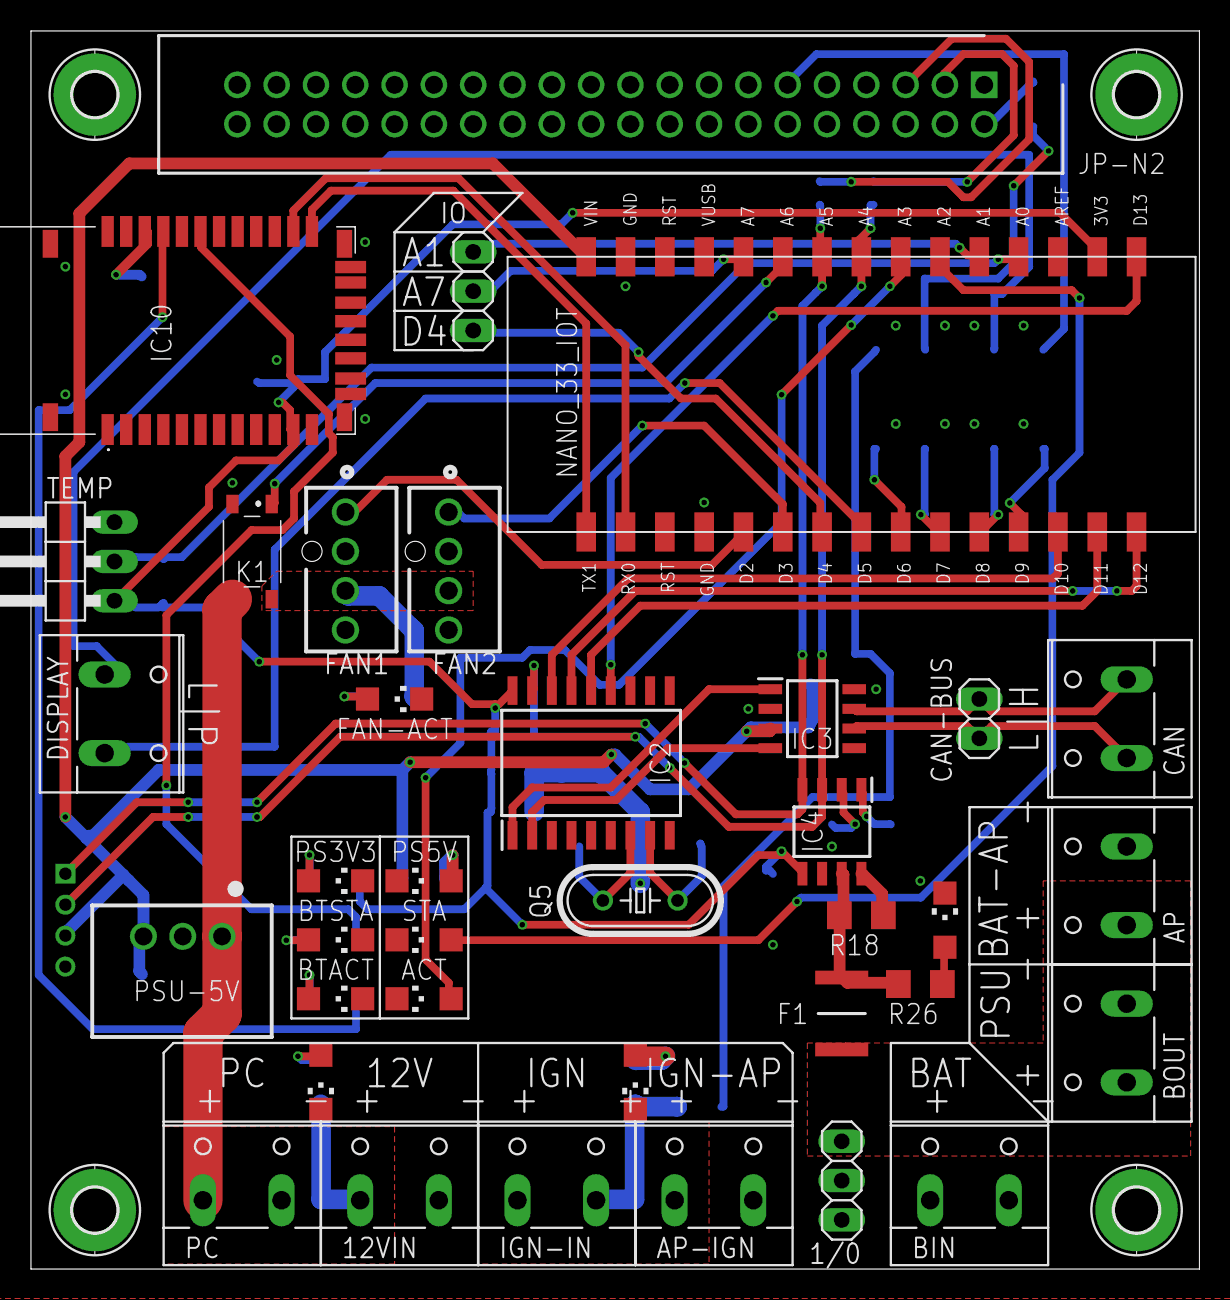
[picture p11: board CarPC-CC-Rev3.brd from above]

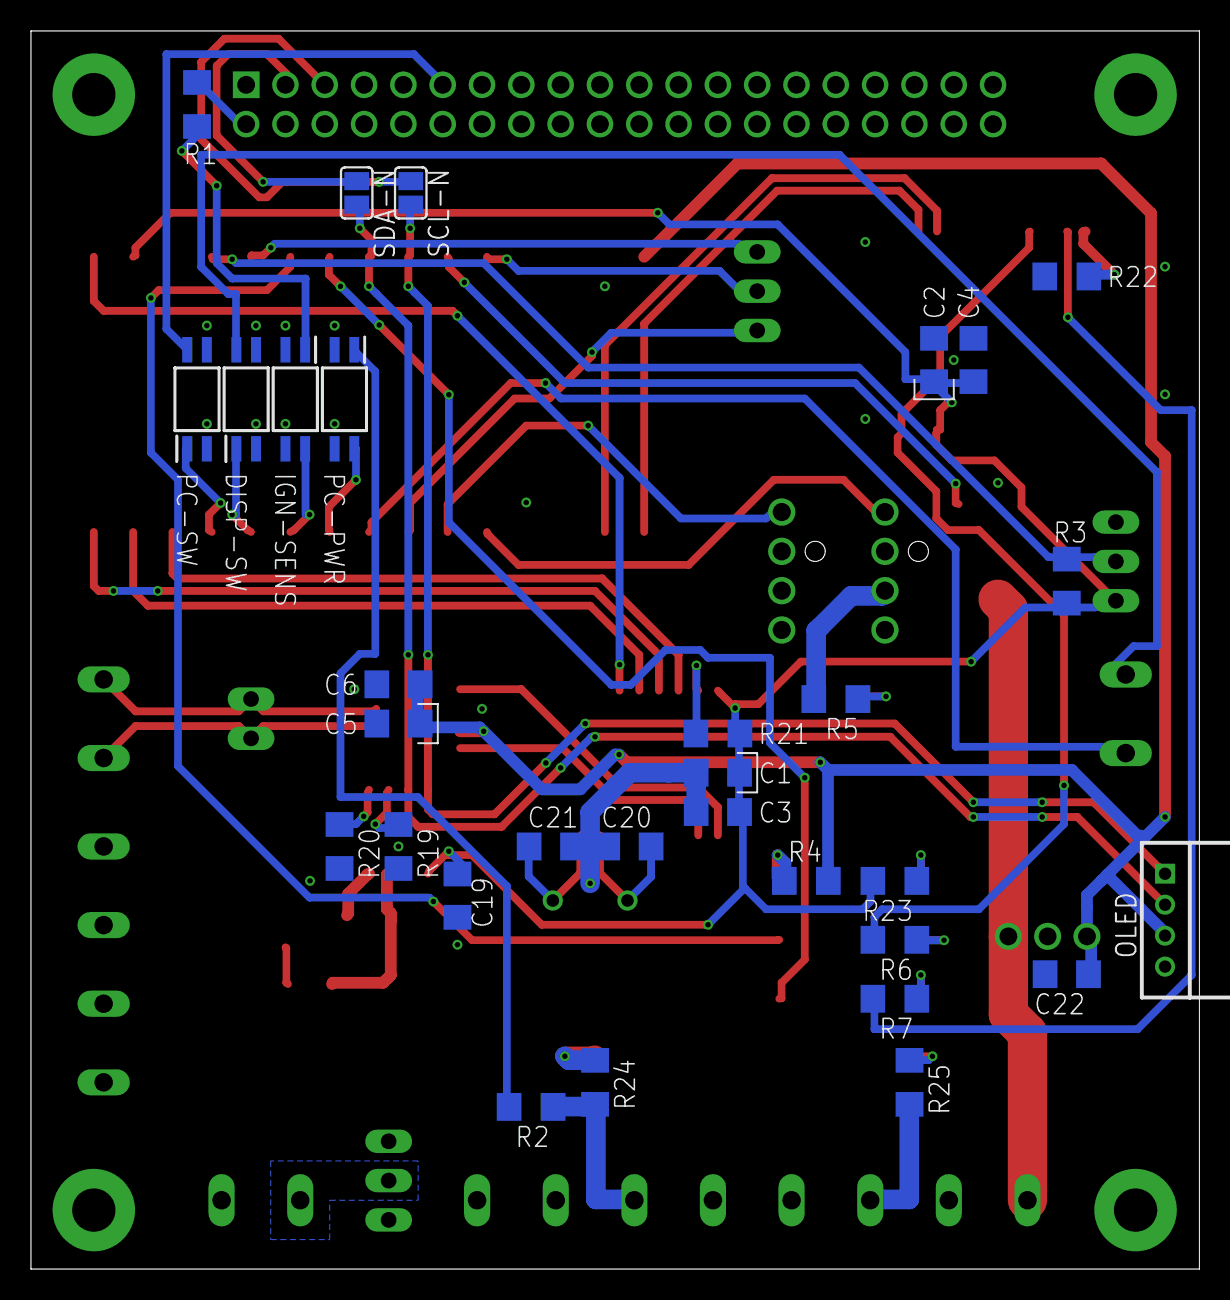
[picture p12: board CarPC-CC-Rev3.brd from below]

Board: 2 copper layers, 75.5 x 80.0 mm, 72 parts (31 on the bottom side), 59 nets.

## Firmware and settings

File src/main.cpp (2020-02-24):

#include <Arduino.h>

/*
  Projektbezogene Header
*/

#include <main.h>
#include <k-can.h>
#include <k-can-messages.h>
#include <k-can-addresses.h>
#include <idrive-controls.h>

#pragma region "Setup"
void setup()
{
    
    pinMode(PIN_IGNITION_INPUT, INPUT_PULLUP);        //Zündungs-Pin
    pinMode(PIN_ODROID_POWER_BUTTON, OUTPUT);         //Opto 2 - Odroid Power Button
    pinMode(PIN_ODROID_POWER_INPUT, INPUT_PULLUP);    //Odroid VOUT Pin als Rückmeldung ob der PC eingeschaltet ist
    pinMode(PIN_ODROID_DISPLAY_POWER_BUTTON, OUTPUT); //Opto 3 - Display Power Button
    pinMode(STATUS_LED, OUTPUT);                      //Status LED
    pinMode(ACT_LED, OUTPUT);                         //Activity LED
    pinMode(PIN_DEBUG, INPUT_PULLUP);                 //Debug Switch Pin
    pinMode(PIN_VU7A_BRIGHTNESS, OUTPUT);             //Display Helligkeitssteuerung
    pinMode(PIN_FAN_RELAY, OUTPUT);                   //Lüfter Relais
    pinMode(LED_BUILTIN, OUTPUT);
    pinMode(A7, OUTPUT);

    analogWrite(A7, 255);
    
    Serial.println("[setup] Startup");

    Serial.begin(serialBaud);

    //Zeitstempel einrichten
    buildtimeStamp();

    
    setupIna();
    //First-Time use only
    //initalSetup();
    setupBluetooth(Serial1, serialBaud);


    //Lüfter einschalten
    digitalWrite(PIN_FAN_RELAY, HIGH);
    setupWifi();
    setupUDP();
    setupRTC();
    setupTemperatureSensors();

    //Display von ganz dunkel nach ganz Hell stellen. Quasi als Test
    for (int i = 0; i <= 255; i++)
    {
        analogWrite(PIN_VU7A_BRIGHTNESS, i);
    }
    analogWrite(STATUS_LED, 255);
    setupCan();
    setupPWM();
}
#pragma endregion

#pragma region "LOOP"
void loop()
{
    //Aktuelle Zeit
    unsigned long currentMillis = millis();
    bool anyPendingActions = odroidStartRequested || odroidShutdownRequested || odroidPauseRequested;

    if (startup)
    {
        //Wenn die Steuerung mit aktiver Zündung startet oder resettet, sollte der Odroid starten
        //Aber nur wenn der Odroid AUS ist aber die Zündung an
        //Wenn der Odroid im Sleep ist, ist odroidRunning ebenfalls Low. Auf diese Art wird er bei Zündung direkt aufgeweckt.
        if (odroidRunning == LOW && ignitionOn == LOW && odroidStartRequested == false)
        {
            Serial.println("[STARTUP] PC aus, Zündung an --> Starte Pc...");
            startOdroid();
        }
        //Start beendet.
        startup = false;
    }

    //Start angefordert
    if (odroidStartRequested)
    {
        if (currentMillis - previousOdroidActionTime >= ODROID_BOOT_HOLD_DELAY)
        {
            odroidStartRequested = false;
            //Zeit merken
            previousOdroidActionTime = currentMillis;
            //Ausgang freigeben
            digitalWrite(PIN_ODROID_POWER_BUTTON, LOW);
            Serial.println("[odroidStartRequested] Start erfolgt.");
            //Aktuellen Counter merken. Ausführung weiterer Aktionen wird pausiert, bis abgewartet wurde.
            startPowerTransitionMillis = millis();
        }
    }
    //Stop angefordert
    if (odroidShutdownRequested)
    {
        if (currentMillis - previousOdroidActionTime >= ODROID_SHUTDOWN_HOLD_DELAY)
        {
            odroidShutdownRequested = false;
            //Zeit merken
            previousOdroidActionTime = currentMillis;
            //Ausgang freigeben
            digitalWrite(PIN_ODROID_POWER_BUTTON, LOW);
            Serial.println("[odroidShutdownRequested] Stop erfolgt.");
            //Aktuellen Counter merken. Ausführung weiterer Aktionen wird pausiert, bis abgewartet wurde.
            startPowerTransitionMillis = millis();
        }
    }

    if (odroidPauseRequested)
    {
        if (currentMillis - previousOdroidPauseTime >= ODROID_STANDBY_DELAY)
        {
            odroidPauseRequested = false;
            Serial.println("[odroidPauseRequested] Standby erfolgt.");
            //Aktuellen Counter merken. Ausführung weiterer Aktionen wird pausiert, bis abgewartet wurde.
            startPowerTransitionMillis = millis();
        }
    }

    //CAN Nachrichten verarbeiten
    checkCan();
    //Konsole
    readConsole();

    //1-Second timer
    if (currentMillis - previousOneSecondTick >= 1000)
    {
        previousOneSecondTick = currentMillis;
        //Zeitstempel Variablen füllen
        buildtimeStamp();
        //Lüfter steuern
        fanControl();
        //Spannung abrufen
        checkIna();
        //Display
        //feedDisplay();
        Serial.println("---------- Update ----------");
        Serial.print("Uhrzeit: ");
        Serial.println(timeString);
        Serial.print("Datum: ");
        Serial.println(dateString);
        Serial.print("Temperatur: ");
        Serial.print(temperature);
        Serial.println("°C");
        Serial.print("Lüftergeschwindigkeit: ");
        Serial.print(map(dynamicDuty,0,MAX_FANDUTY,0,100));
        Serial.println("%");
        Serial.print("Spannung: ");
        Serial.print(busvoltage);
        Serial.println("V");
        Serial.print("Zündung: ");
        Serial.println(!ignitionOn);
        Serial.print("PC: ");
        Serial.println(odroidRunning);
        Serial.print("Action: ");
        switch (pendingAction)
        {
        case ODROID_START:
            Serial.println("Starten");
            break;
        case ODROID_STOP:
            Serial.println("Stoppen");
            break;
        case NONE:
            Serial.println("Idle.");
            break;
        default:
            break;
        }
    }

    //Zeit alle 60 Sekunden aktualisieren bzw. Wifi Verbindung aufbauen. Da das blockieren kann, wird das nur ausgeführt, wenn keine Aktion gerade ansteht
    if (currentMillis - previousRtcUpdateMillis >= 60000 && !anyPendingActions)
    {
        previousRtcUpdateMillis = currentMillis;
        Serial.println("[WiFi] Verbindung checken");
        setupWifi();
        Serial.println("[RTC] Zeit aktualisieren");
        updateTime();
    }

    //Status-LED
    if (currentMillis - statusLedMillis >= statusLedInterval)
    {
        statusLedMillis = currentMillis;
        if (odroidRunning == HIGH)
        {
            statusLedBrightness = 255;
        }
        else
        {
            if (canbusEnabled)
            {
                statusLedInterval = 100UL;
            }
            else
            {
                statusLedInterval = 500UL;
            }
            statusLedBrightness += statusLedStep;
            if (statusLedBrightness <= 0 || statusLedBrightness >= 255)
            {
                statusLedStep = -statusLedStep;
            }
        }

        analogWrite(STATUS_LED, statusLedBrightness);
    }

    //Aktivitäts-LED
    if (currentMillis - actLedMillis >= actLedInterval)
    {
        actLedMillis = currentMillis;
        switch (pendingAction)
        {
        case ODROID_STOP:
            actLedInterval = 100UL;

            break;
        case ODROID_START:
            actLedInterval = 10UL;
            break;

        default:
            break;
        }
        actLedBrightness += actLedStep;
        //Richtung umkehren bei MIN oder MAX Wert
        if (actLedBrightness <= 0 || actLedBrightness >= 255)
        {
            actLedStep = -actLedStep;
        }
        analogWrite(ACT_LED,actLedBrightness);
    }

    //Allgemeine Funktionen. Nur ausführen, wenn Zyklus erreicht wurde und keine ausstehenden Aktionen laufen, die ein zeitkritisches Verändern der Ausgänge beinhalten.
    if (currentMillis - previousMainTaskTime >= CYCLE_DELAY && !anyPendingActions)
    {
        //Zündung überprüfen
        checkIgnitionState();
        //Ein- und Ausgänge überprüfen
        checkPins();

        //Zeit merken
        previousMainTaskTime = currentMillis;
        //Sperrung freigeben, wenn Timeout abgelaufen ist
        switch (pendingAction)
        {
        case ODROID_STOP:
            if (currentMillis - startPowerTransitionMillis >= SHUTDOWN_WAIT_DELAY)
            {
                Serial.println("[LOOP] Shutdown Wartezeit abgelaufen");
                pendingAction = NONE;
                //Wurde der Start vorgemerkt, ausführen und zurücksetzen
                if (queuedAction == ODROID_START)
                {
                    startOdroid();
                    queuedAction = NONE;
                }
            }
            break;
        case ODROID_START:
            if (currentMillis - startPowerTransitionMillis >= STARTUP_WAIT_DELAY)
            {
                Serial.println("[LOOP] Start Wartezeit abgelaufen");
                pendingAction = NONE;
                //Wurde Stopp vorgemerkt, ausführen und zurücksetzen
                if (queuedAction == ODROID_STOP)
                {
                    stopOdroid();
                    queuedAction = NONE;
                }
            }
            break;
        case ODROID_STANDBY:
            if (currentMillis - startPowerTransitionMillis >= ODROID_STANDBY_DELAY)
            {
                Serial.println("[LOOP] Stand-by Wartezeit abgelaufen");
                pendingAction = NONE;
            }
            break;

        default:
            //Keine Aktion aktiv.

            //Sicherheitshalber zurücksetzen
            queuedAction = NONE;
            break;
        }
    }
}
#pragma endregion

void checkPins()
{
    //Status des Zündungspins abrufen
    ignitionOn = digitalRead(PIN_IGNITION_INPUT);
    //Staus Odroid Vcc pin
    odroidRunning = !digitalRead(PIN_ODROID_POWER_INPUT);

    //Status Debug-Pin
    debugMode = !digitalRead(PIN_DEBUG);

    //Prüfe alle Faktoren für Start, Stopp oder Pause des Odroid.
    checkIgnitionState();
}

void checkIgnitionState()
{

    //Wenn der Status der Zündung sich verändert hat.
    if (ignitionOn != lastIgnitionState)
    {
        //Zündung ist an aber PC ist aus.
        if (ignitionOn == LOW && odroidRunning == LOW)
        {
            //PC starten.
            startOdroid();
        }
    }
    //Letzten Status merken.
    lastIgnitionState = ignitionOn;
}

void startOdroid()
{
    //Zeitstempel
    Serial.print(timeStamp + '\t');
    Serial.print("[startOdroid] Odroid Status:");
    Serial.println(odroidRunning == LOW ? "AUS" : "AN");
    //Mehrfachen Aufruf verhindern - auch wenn der PC bereits läuft
    if (odroidStartRequested || odroidRunning || pendingAction != NONE)
    {
        return;
    }

    //Starten
    odroidStartRequested = true;
    pendingAction = ODROID_START;
    digitalWrite(PIN_ODROID_POWER_BUTTON, HIGH);
    //Zeitstempel
    Serial.print(timeStamp + '\t');
    Serial.println("[startOdroid] Start angefordert.");
    previousOdroidActionTime = millis();
}

void pauseOdroid()
{
    //Wenn der PC aus ist, dann brauchen wir auch nicht Pause drücken.... Wir gehen auch einfach mal davon aus, dass er aus ist.
    //Wenn auch noch eine Stand-By Anforderung ausstehend ist, könnte ein erneutes Drücken den Start wieder auslösen.
    if (odroidPauseRequested || !odroidRunning || pendingAction != NONE)
    {
        return;
    }
    pendingAction = ODROID_STANDBY;
    digitalWrite(PIN_ODROID_DISPLAY_POWER_BUTTON, HIGH);
    digitalWrite(PIN_ODROID_POWER_BUTTON, HIGH);
    Serial.println("[pauseOdroid] Stand-By angefordert");
    //Kurze Verzögerung - kurzer Tastendruck für display und Odroid
    delay(ODROID_STANDBY_HOLD_DELAY);
    digitalWrite(PIN_ODROID_DISPLAY_POWER_BUTTON, LOW);
    digitalWrite(PIN_ODROID_POWER_BUTTON, LOW);
    odroidPauseRequested = true;
    previousOdroidPauseTime = millis();
}

void stopOdroid()
{
    //Zeitstempel
    Serial.print(timeStamp + '\t');
    Serial.print("[stopOdroid] Odroid Status:");
    Serial.println(odroidRunning == LOW ? "AUS" : "AN");
    //Mehrfachen Aufruf verhindern - auch wenn der PC bereits aus ist. Das würde diesen nämlich einschalten.
    if (odroidShutdownRequested || !odroidRunning || pendingAction != NONE)
    {
        return;
    }

    //Herunterfahren
    odroidShutdownRequested = true;
    pendingAction = ODROID_STOP;

    digitalWrite(PIN_ODROID_POWER_BUTTON, HIGH);
    Serial.println("[stopOdroid] Herunterfahren angefordert");

    previousOdroidActionTime = millis();
}

void readConsole()
{
    if (Serial.available() > 0)
    {
        String command = Serial.readStringUntil('\n');
        if (command == "pc.stop")
        {
            stopOdroid();
        }
        if (command == "pc.start")
        {
            startOdroid();
        }
        if (command == "pc.pause")
        {
            pauseOdroid();
        }
        if (command == "car.testcan")
        {
        }
        if (command == "debug.activate")
        {
            debugMode = true;
        }
        if (command == "debug.deactivate")
        {
            debugMode = false;
        }
    }
}

void fanControl()
{
    //Lüfter einschalten, wenn PC läuft. Ansonsten ausschalten.
    if (odroidRunning == HIGH)
    {
        digitalWrite(PIN_FAN_RELAY, HIGH);
    }
    else
    {
        digitalWrite(PIN_FAN_RELAY, LOW);
    }

    //Temperaturabhängige Lüftersteuerung
    temperature = checkTemperature();

    if (temperature < 20)
    {
        dynamicDuty = MIN_FANDUTY;
        digitalWrite(PIN_FAN_RELAY, LOW);
    }
    if (temperature > 40)
    {
        dynamicDuty = MAX_FANDUTY;
    }

    if (temperature >= 20 && temperature <= 40)
    {
        dynamicDuty = map((int)temperature, 20, 40, MIN_FANDUTY, MAX_FANDUTY);
        
    }
    setFanDutyCycle(dynamicDuty);
}

#pragma region "Bluetooth"

void setupBluetooth(Uart serial, int serialBaud)
{
    // Bluetooth Modul
    //Serial1 (0/1 für BT Modul benutzen)
    Serial.println("[setup] Serial 1 (Pin RX0,TX1)");
    serial.begin(serialBaud);
    Serial.println("[setup] Setup BT Library");
    BPMod = new BPLib(serial);
}

void initalSetup()
{
    //Command Reference: https://cdn.sparkfun.com/datasheets/Wireless/Bluetooth/bluetooth_cr_UG-v1.0r.pdf
    Serial1.write("$$$\r\n");
    //Wait for device response
    delay(1000);
    //Set as a Combo device
    Serial1.write("SH,0230\r\n");
    delay(1000);
    //Enable HID Profile
    Serial1.write("S~,6\r\n");
    delay(1000);
    //Set PIN Mode
    Serial1.write("SA,1\r\n");
    delay(1000);
    //Set device name
    Serial1.write("SN,IDRIVECTRL\r\n");
    delay(1000);
    //Clear any addresses
    //SR,Z
    //Store MAC Address
    //SR,001A7DDA7113
    //Bond to the Address
    //SX,1
    //Set Auto Reconnect Mode without pulling a GPIO
    Serial1.print("SM,5\r\n");
    delay(1000);
    //End
    Serial1.write("---\r\n");
}
#pragma endregion

#pragma region "CAN-Processor"
void setupCan()
{
    if (canModuleStatus != CAN_OK)
    {
        Serial.println("[CAN MODUL] Nicht initialisiert. Initialisiere...");
        delay(5000);
        canModuleStatus = CAN.begin(CAN_100KBPS);
        if (canModuleStatus != CAN_OK)
        {
            Serial.println("[CAN MODUL] Initialisierung fehlgeschlagen.");
            delay(5000);
        }
    }
    else
    {
        //nix
    }
}
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

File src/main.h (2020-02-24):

#pragma once
#include <Arduino.h>
#include <OneWire.h>
#include <DallasTemperature.h>
#include <SPI.h>
#include <mcp_can.h>
#include <BPLib.h>

#include <Adafruit_INA219.h>

#include <SeeedOLED.h>

#include <WiFiNINA.h>
#include <WiFiUdp.h>
#include "arduino_secrets.h"
#include <ArduinoBLE.h>
#include <RTCZero.h>

/* ----------------- PWM, FAN */

//Maximaler dutycycle also frequenz. 1919 entspricht 100%DC @ 25kHz
const int MAX_FANDUTY = 5000;

//Minimaler cycle.
const int MIN_FANDUTY = 0;

//PWM Setup
void setupPWM();
//Set Duty Cycle
void setFanDutyCycle(int pcCycle);

/* ----------------- OLED */
//Initialize the display.
void setupOled();

/* ---------------- RTC, Connectivity */
//Sets up and connects wifi according to the constants defined in "arduino_secrets.h" as "SECRET_SSID" and "SECRET_PASS"
//This function throttles itself so it only tries to connect after a certain delay defined in "connect_delay"
void setupWifi();
//Setup UDP Connectivity
void setupUDP();
//Connects to a NTP server via UDP and retrieves the current time.
void updateTime();
//RTC Init
void setupRTC();
//Timestamp builder
void buildtimeStamp();
//Send NTP Packet
unsigned long sendNTPpacket(IPAddress& address);

// local port to listen for UDP packets
unsigned int localPort = 2390;
// de.pool.ntp.org NTP server 88.198.17.248
IPAddress timeServer(88, 198, 17, 248);
// NTP time stamp is in the first 48 bytes of the message
const int NTP_PACKET_SIZE = 48;
//buffer to hold incoming and outgoing packets
byte packetBuffer[NTP_PACKET_SIZE];
// A UDP instance to let us send and receive packets over UDP
WiFiUDP Udp;

//Stores the result of a connection attempt.
int wifiStatus = WL_IDLE_STATUS;
//Seconds of delay between retry attempts
const int connect_delay = 10;
//Timer
unsigned long previousConnectionAttempt = 0;

//RTC
RTCZero rtc; 

/* -------------------- Voltage Monitoring */
Adafruit_INA219 ina219;
//Establish connection with the INA219 chip and initialize it
void setupIna();
//Retrieves all the data and fills it into the variables:
//float shuntvoltage = Reads the voltage between V- and V+. This is the measured voltage drop across the shunt resistor.
//float busvoltage = Reads the voltage between GND and V-. This is the total voltage seen by the circuit under test. (Supply voltage -shunt voltage).
//float Reads the current, derived via Ohms Law from the measured shunt voltage
//float loadvoltage = bus voltage while also taking into account the shunt voltage
//float power_mW = power
void checkIna();

float shuntvoltage = 0;
float busvoltage = 0;
float current_mA = 0;
float loadvoltage = 0;
float power_mW = 0;

/* Temperature */
const int ONE_WIRE_BUS = A0;    //DATA PORT DALLAS 18B50
const int TEMP_RESOLUTION = 11; //TEMPERATURE RESOLUTION

OneWire oneWire(ONE_WIRE_BUS);
DallasTemperature sensors(&oneWire);
DeviceAddress firstDeviceAddress;

float temperature = 0.0;
float rawtemp = 0.0;

//Setup sensors
void setupTemperatureSensors();
//retrieve the current temperature of sensor
float checkTemperature();

/*------------- Functions -------------*/
//Status der Zündung abrufen und entsprechende Aktionen auslösen
void checkIgnitionState();
//Start bzw. Aufwecken
void startOdroid();
//Sofortiges geordnetes Herunterfahren
void stopOdroid();
//Odroid in Sleep versetzen und Display ausschalten
void pauseOdroid();
//Ein- und Ausgänge prüfen
void checkPins();
//Zeitstempel bauen
void buildtimeStamp();
//Mausrad simulieren, je nachdem in welche Richtung der iDrive Knopf gedreht wurde.
void scrollScreen();
//Taste drücken und sofort wieder freigeben
void sendKey(uint8_t keycode);
//Interaktion mit serieller Konsole
void readConsole();
//Lüftersteuerung
void fanControl();
//Display füllen
void feedDisplay();


/*------------- PIN DEFINITIONS -------------*/
//Opto 2 - Zündung Aktiv
const int PIN_IGNITION_INPUT = 6;
//Eingang Odroid Power Button. Wenn dieser HIGH ist, ist der Odroid aktiv.
const int PIN_ODROID_POWER_INPUT = 7;
//Ausgang Odroid Power Button
const int PIN_ODROID_POWER_BUTTON = 9;
//Power Button vom Display
const int PIN_ODROID_DISPLAY_POWER_BUTTON = 8;
//CAN CS Pin
const int SPI_CS_PIN = 10;
//Pin für Display Helligkeit
const int PIN_VU7A_BRIGHTNESS = 5;
//Pin für Debug Switch
const int PIN_DEBUG = 4;
//PWM Pin #1
const int PWM_PIN_1 = 2;
//PWM Pin #2
const int PWM_PIN_2 = 3;
//Pin für Steuerung des Lüfter Relais via OK
const int PIN_FAN_RELAY = A6;
//Status LED
const int STATUS_LED = A2;
//Aktivitäts-LED
const int ACT_LED = A3;
//Temperatursensor
const int TEMP_SENSOR = A0;
//CAN Interrupt
//const int CAN_INT = A1; //A1 = INT2

/*------------- Fields / Vars -------------*/


//Zeitstempel für Sekundentimer
unsigned long previousOneSecondTick = 0;

//Mögliche Aktionen
enum PendingAction
{
  ODROID_START,
  ODROID_STOP,
  ODROID_STANDBY,
  NONE
};
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

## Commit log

2020-01-04 Added PWM for FAN ctrl. Added LED Outputs
2020-01-17 Added schematics
    [20V-3V3-Divider.sch, CAN-Interface.brd, CAN-Interface.sch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]
2020-02-23 Cleanup & Bugfixes. Functionality 100% Completed
    [k-can.h, main.cpp, main.h]
2020-02-23 Eagle Files updated to actual working copy
    [20V-3V3-Divider.sch, CAN-Interface.brd, CAN-Interface.sch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]
2020-02-23 Added Silkscreens for documentation
2020-02-23 Added Gerber & Production Files
    [copper_bottom.gbr, copper_top.gbr, drill_1_16.xln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]
2020-02-23 Wiring Diagram
2020-02-23 Readme Update: Introduced wiring explanation
    ...Still not complete...
2020-02-23 I2C Info added
2020-02-23 I2C Info & Bottom view render
2020-02-24 Update README.md
    Added Info about LEDs and Diagnostics under "Signalling & Diagnostics"
2020-02-24 Fixes to the BT setup routine.
    [main.cpp]
2020-02-24 Error in schemic and board: using 5v rail now
    [CarPC-CC-Rev3.brd, CarPC-CC-Rev3.sch]
2020-02-24 FIX: Swapped D9 with D8.
    [main.cpp, main.h]
